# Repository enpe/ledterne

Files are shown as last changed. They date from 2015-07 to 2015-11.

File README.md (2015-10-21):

# LEDterne

## Required Equipment

- Suggested hardware lists:
	1. [mikrocontroller.net][0]
- Atmel AVRISP MKII ([Amazon][1])
- Evaluation board ([ehajo][2], [Pollin][3], [Amazon][4])
- Adapter cable, 10P-to-6P ([mikocontroller.net][7], [Amazon 1][5], [Amazon 2][6])
- Power supply (~9V)
- Bread board ([Amazon][8])
- ATMEGA8-16PU ([Amazon][9])
- Steckbrücken 
- Multimeter
- Resistors
- LEDs (e.g. RGB)
- Software (compiler, etc.) ([mikrocontroller.net][20])

## TODO

- Experiment with LEDs
	- Adjust series resistors for balanced LED brightness of the different colors
	- Try diffusing light from the LEDs
- Add some interesting animations
- Add a push button for switching between a number of animations, constant colors etc.
	- Can use pin PD3's external interrupt capabilities instead of polling one of the other free pins
- Make it battery-driven
- Maybe make the PWM smarter for improved energy saving
	- Alternative 1:
		- Avoid generating interrupts for every single possible step in a PWM cycle
		- Compute only the required timeout periods for all 3×5 outputs instead
	- Alternative 2 (easier than 1):
		- Avoid generating interrupts for every single possible step in a PWM cycle
		- Compute only the required timeout periods for all (currently 32) different duty cycles that we actually use
		- This is not as efficient as alternative 1, but it is much simpler to implement since it is not data-dependent (does not change with the desired LED brightness (i.e. with the animations))
- Maybe improve PWM resolution for smoother fading
- Maybe implement the animations using coroutines/generators instead of letting the animation do the diplay update
	- https://en.wikipedia.org/wiki/Generator_%28computer_science%29
	- http://www.chiark.greenend.org.uk/~sgtatham/coroutines.html

### Battery holder and rod
- Dimensions of [mignon/AA batteries][21]:
	- Diameter:  13.5-14.5 mm
    - Length:    49.2-50.5 mm
- General idea:
    1. Rod of the lantern
    	- Thin aluminum tube (outer diameter <= 10mm).
    	- Drill a small hole near the top end of the rod (wire outlet + hook for
    	  lantern).
    	- Close the top end with a small cap (or leave it open).
    	- Take 2-3 corks and drill holes into the centers to fit the rod.
    	- Cut outside part of the corks to fit (tightly) into the tube of 
    	  battery holder.
    	- Slide the corks over the lower end of the rod.
    	- Insert 2 wires from lower end of the rod to the outlet at the top end.
    2. Battery holder
		- Tube with inner diameter of ~15-16 mm.
		- In the first third of the tube, drill a hole for a small switch.
		- Add 2 wires: one from switch to the lower end of the tube the other
		  from one end of the tube to the other.
		- Connect the switch with one wire of the rod, and connect the remaining
		  two wires
		- Connect upper end of the battery holder with the rod.
		- Fill with 3xAA batteries.
		- Add a spring at the lower end and connect it to the wire.
		- Close lower end with a plastic cap (Lamellenstopfen)
- Other DIY project for battery holders (in no particular order):
	- http://makezine.com/2009/08/14/how-to-free-diy-battery-holders/
	- http://makezine.com/2015/08/02/make-a-stylish-flashlight-out-of-kitchen-trash/
	- http://www.instructables.com/id/Bicycle-Battery-Holder-3-x-AA/
	- http://www.instructables.com/id/Easy-custom-battery-holders/
	- http://www.instructables.com/id/Easy-DIY-Battery-Holder/
	- http://www.instructables.com/id/PVC-tube-battery-AA-battery-holder/
	- http://www.pcbheaven.com/projectpages/DIY_Battery_Pack/

[0]: http://www.mikrocontroller.net/articles/AVR-Tutorial:_Equipment
[1]: http://www.amazon.de/Atmel-Programmer-ATMEL-AVR-ISP-MKII/dp/B00CASCN2S
[2]: http://www.ehajo.de/ateval-atmel-evaluationboard.html 
[3]: http://www.pollin.de/shop/dt/NTI5OTgxOTk-/Bausaetze_Module/Entwicklerboards/ATMEL_Evaluations_Board_V2_0_1_Fertigmodul.html
[4]: http://www.amazon.de/Atmel-Fertiggerät-Atmel-Evaluations-Board-V2-0/dp/B004BMJZ0O
[5]: http://www.amazon.de/Convert-Standard-Adapter-STK500-AVRISP/dp/B00P783JIU
[6]: http://www.amazon.de/Adapter-Kit-10polig-Atmel-Programmer/dp/B004D2TFYI
[7]: http://www.mikrocontroller.net/articles/AVR_In_System_Programmer#ISP
[8]: http://www.amazon.de/Steckbrett-Breadboard-Experimentierboard-Steckplatine-Kontakte/dp/B009P04XWW
[9]: http://www.amazon.de/ATMEGA8-16PU-Atmel-Microcontroller-MEGA-DIP-28/dp/9827046934
[20]: http://www.mikrocontroller.net/articles/AVR_und_Linux
[21]: https://de.wikipedia.org/wiki/Mignon_%28Batterie%29

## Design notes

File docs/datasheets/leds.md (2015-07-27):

# SMD RGB LEDs

- bought from [Segor](http://www.segor.de/#Q%3DLED5252RGB%26M%3D1)
- no clear indication of a model, so no datasheet
- conducted our own measurement of forward voltages given a fixed forward current:

| Fwd current | Fwd voltage R | Fwd voltage G | Fwd voltage B |
|---|---|---|---|
| 20 mA | 2.08 V | 3.39 V | 3.14 V |
| 25 mA | 2.12 V | 3.45 V | 3.21 V |
| 30 mA | 2.15 V | 3.49 V | 3.26 V |

- every single one of the 3 LEDs inside that package can be controlled independently

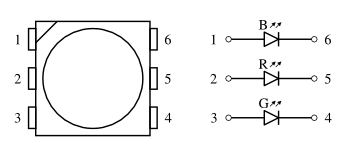
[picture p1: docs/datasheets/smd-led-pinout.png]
LED pinout


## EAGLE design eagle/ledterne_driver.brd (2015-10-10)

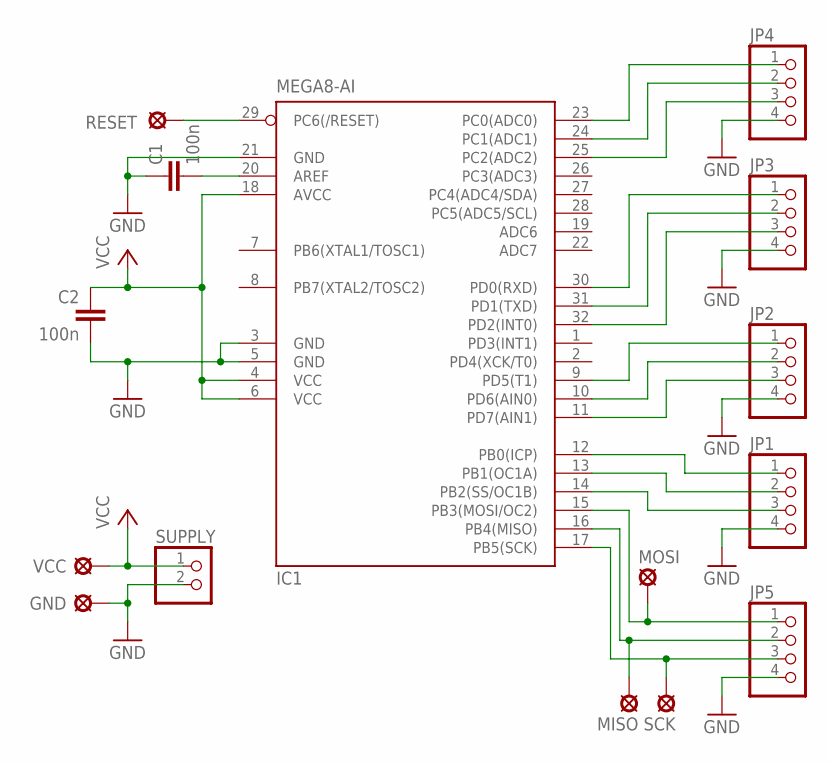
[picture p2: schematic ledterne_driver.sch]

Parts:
C1, C2: 100n; C0805K
GND: LSP10
IC1: MEGA8-AI; TQFP32-08
JP1, JP2, JP3, JP4, JP5: PINHD-1X4/90; 1X04/90
MISO: LSP10
MOSI: LSP10
RESET: LSP10
SCK: LSP10
SUPPLY: PINHD-1X2; 1X02
VCC: LSP10

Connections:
GND: C1.1, C2.2, GND.MP, IC1.3 (GND), IC1.5 (GND), IC1.21 (GND), JP1.4, JP2.4, JP3.4, JP4.4, JP5.4, SUPPLY.2
MISO: IC1.16 (PB4(MISO)), JP5.2, MISO.MP
MOSI: IC1.15 (PB3(MOSI/OC2)), JP5.1, MOSI.MP
unnamed: C1.2, IC1.20 (AREF)
unnamed: IC1.14 (PB2(SS/OC1B)), JP1.3
unnamed: IC1.13 (PB1(OC1A)), JP1.2
unnamed: IC1.12 (PB0(ICP)), JP1.1
unnamed: IC1.11 (PD7(AIN1)), JP2.3
unnamed: IC1.10 (PD6(AIN0)), JP2.2
unnamed: IC1.9 (PD5(T1)), JP2.1
unnamed: IC1.30 (PD0(RXD)), JP3.1
unnamed: IC1.31 (PD1(TXD)), JP3.2
unnamed: IC1.32 (PD2(INT0)), JP3.3
unnamed: IC1.23 (PC0(ADC0)), JP4.1
unnamed: IC1.24 (PC1(ADC1)), JP4.2
unnamed: IC1.25 (PC2(ADC2)), JP4.3
RESET: IC1.29 (PC6(/RESET)), RESET.MP
SCK: IC1.17 (PB5(SCK)), JP5.3, SCK.MP
VCC: C2.1, IC1.4 (VCC), IC1.6 (VCC), IC1.18 (AVCC), SUPPLY.1, VCC.MP

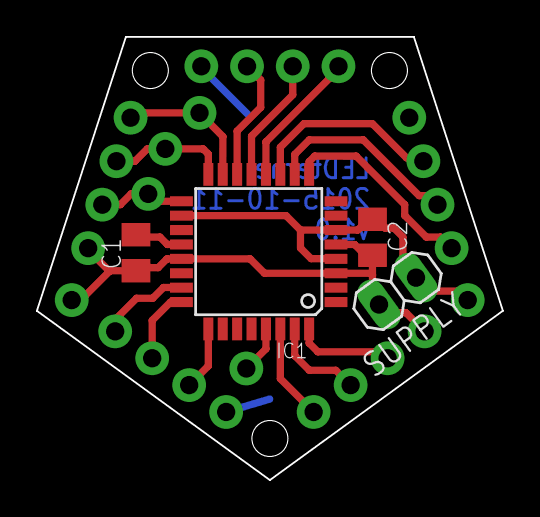
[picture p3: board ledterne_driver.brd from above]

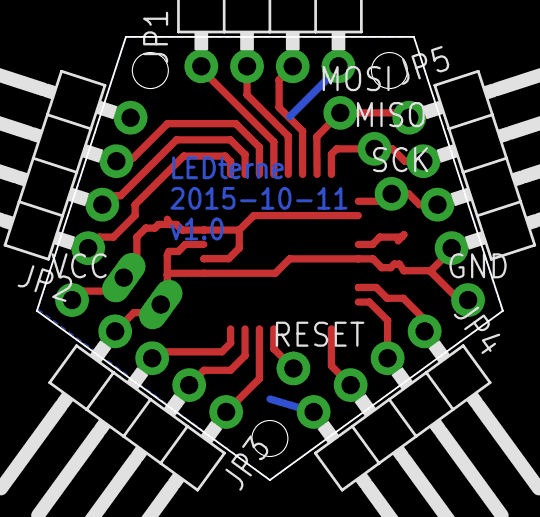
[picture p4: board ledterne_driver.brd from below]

Board: 2 copper layers, 25.9 x 24.6 mm, 15 parts (11 on the bottom side), 19 nets.

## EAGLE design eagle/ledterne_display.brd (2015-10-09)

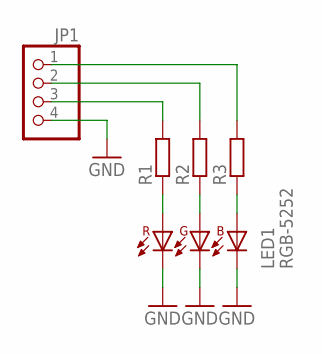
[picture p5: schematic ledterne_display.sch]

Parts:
JP1: PINHD-1X4; 1X04
LED1: RGB-5252; SMD_5252
R1, R2, R3: R-EU_R0805; R0805

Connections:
GND: JP1.4, LED1.P4 (CGREEN), LED1.P5 (CRED), LED1.P6 (CBLUE)
LED_B: JP1.1, R3.2
LED_G: JP1.2, R2.2
LED_R: JP1.3, R1.2
unnamed: LED1.P2 (ARED), R1.1
unnamed: LED1.P3 (AGREEN), R2.1
unnamed: LED1.P1 (ABLUE), R3.1

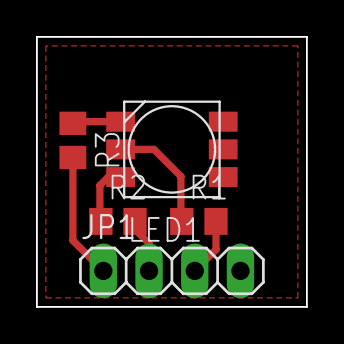
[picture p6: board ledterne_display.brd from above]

Board: 2 copper layers, 15.0 x 15.0 mm, 5 parts (0 on the bottom side), 7 nets.

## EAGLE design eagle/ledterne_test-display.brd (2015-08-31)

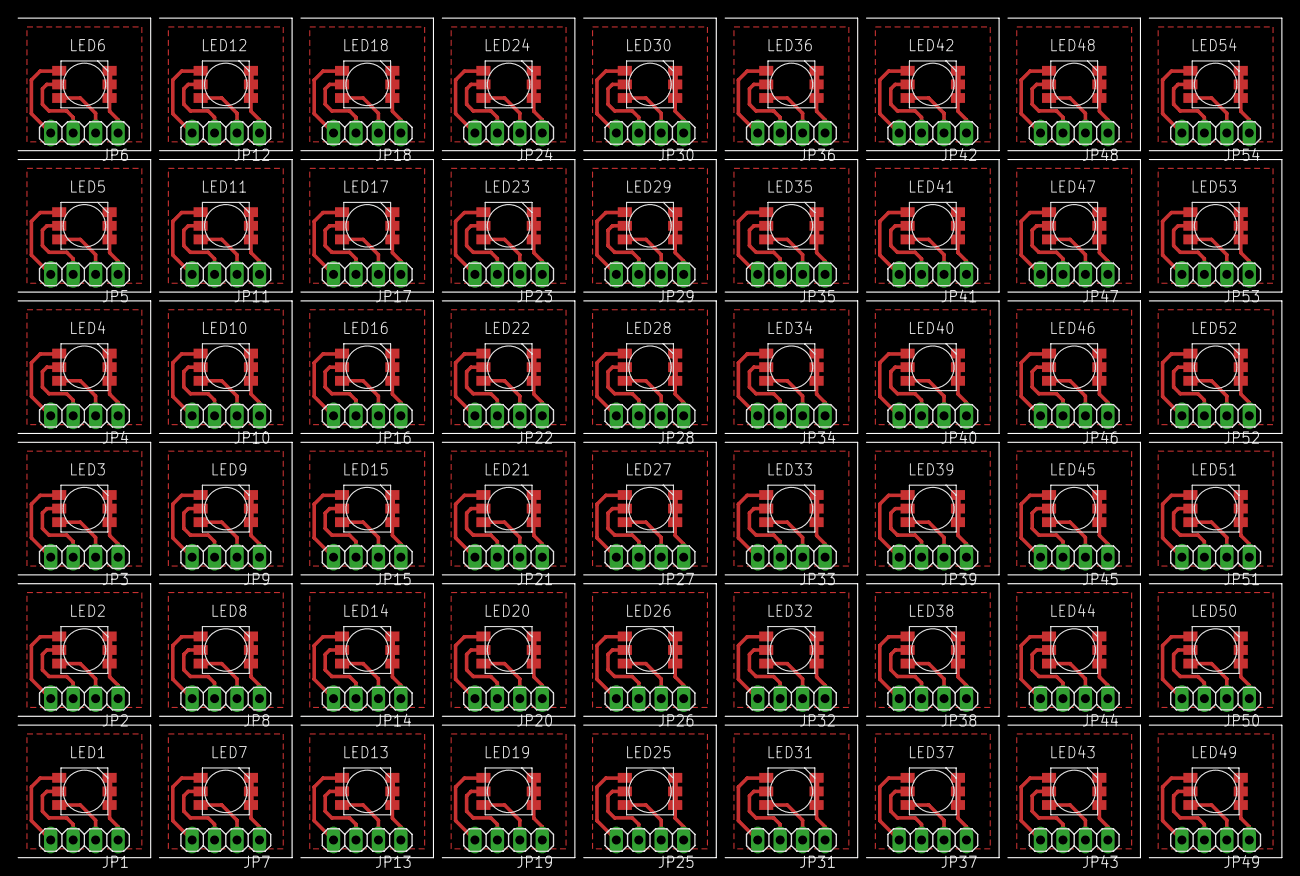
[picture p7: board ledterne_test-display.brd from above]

Board: 2 copper layers, 143.0 x 95.0 mm, 108 parts (0 on the bottom side), 216 nets.

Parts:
JP1, JP2, JP3, JP4, JP5, JP6, JP7, JP8, JP9, JP10, JP11, JP12, JP13, JP14, JP15, JP16, JP17, JP18, JP19, JP20, JP21, JP22, JP23, JP24, JP25, JP26, JP27, JP28, JP29, JP30, JP31, JP32, JP33, JP34, JP35, JP36, JP37, JP38, JP39, JP40, JP41, JP42, JP43, JP44, JP45, JP46, JP47, JP48, JP49, JP50, JP51, JP52, JP53, JP54: 1X04
LED1, LED2, LED3, LED4, LED5, LED6, LED7, LED8, LED9, LED10, LED11, LED12, LED13, LED14, LED15, LED16, LED17, LED18, LED19, LED20, LED21, LED22, LED23, LED24, LED25, LED26, LED27, LED28, LED29, LED30, LED31, LED32, LED33, LED34, LED35, LED36, LED37, LED38, LED39, LED40, LED41, LED42, LED43, LED44, LED45, LED46, LED47, LED48, LED49, LED50, LED51, LED52, LED53, LED54: RGB-5252; SMD_5252

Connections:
GND: JP1.1, LED1.P1, LED1.P2, LED1.P3
GND1: JP2.1, LED2.P1, LED2.P2, LED2.P3
GND2: JP3.1, LED3.P1, LED3.P2, LED3.P3
GND3: JP4.1, LED4.P1, LED4.P2, LED4.P3
GND4: JP5.1, LED5.P1, LED5.P2, LED5.P3
GND5: JP6.1, LED6.P1, LED6.P2, LED6.P3
GND6: JP7.1, LED7.P1, LED7.P2, LED7.P3
GND7: JP8.1, LED8.P1, LED8.P2, LED8.P3
GND8: JP9.1, LED9.P1, LED9.P2, LED9.P3
GND9: JP10.1, LED10.P1, LED10.P2, LED10.P3
GND10: JP11.1, LED11.P1, LED11.P2, LED11.P3
GND11: JP12.1, LED12.P1, LED12.P2, LED12.P3
GND12: JP13.1, LED13.P1, LED13.P2, LED13.P3
GND13: JP14.1, LED14.P1, LED14.P2, LED14.P3
GND14: JP15.1, LED15.P1, LED15.P2, LED15.P3
GND15: JP16.1, LED16.P1, LED16.P2, LED16.P3
GND16: JP17.1, LED17.P1, LED17.P2, LED17.P3
GND17: JP18.1, LED18.P1, LED18.P2, LED18.P3
GND18: JP19.1, LED19.P1, LED19.P2, LED19.P3
GND19: JP20.1, LED20.P1, LED20.P2, LED20.P3
GND20: JP21.1, LED21.P1, LED21.P2, LED21.P3
GND21: JP22.1, LED22.P1, LED22.P2, LED22.P3
GND22: JP23.1, LED23.P1, LED23.P2, LED23.P3
GND23: JP24.1, LED24.P1, LED24.P2, LED24.P3
GND24: JP25.1, LED25.P1, LED25.P2, LED25.P3
GND25: JP26.1, LED26.P1, LED26.P2, LED26.P3
GND26: JP27.1, LED27.P1, LED27.P2, LED27.P3
GND27: JP28.1, LED28.P1, LED28.P2, LED28.P3
GND28: JP29.1, LED29.P1, LED29.P2, LED29.P3
GND29: JP30.1, LED30.P1, LED30.P2, LED30.P3
GND30: JP31.1, LED31.P1, LED31.P2, LED31.P3
GND31: JP32.1, LED32.P1, LED32.P2, LED32.P3
GND32: JP33.1, LED33.P1, LED33.P2, LED33.P3
GND33: JP34.1, LED34.P1, LED34.P2, LED34.P3
GND34: JP35.1, LED35.P1, LED35.P2, LED35.P3
GND35: JP36.1, LED36.P1, LED36.P2, LED36.P3
GND36: JP37.1, LED37.P1, LED37.P2, LED37.P3
GND37: JP38.1, LED38.P1, LED38.P2, LED38.P3
GND38: JP39.1, LED39.P1, LED39.P2, LED39.P3
GND39: JP40.1, LED40.P1, LED40.P2, LED40.P3
GND40: JP41.1, LED41.P1, LED41.P2, LED41.P3
GND41: JP42.1, LED42.P1, LED42.P2, LED42.P3
GND42: JP43.1, LED43.P1, LED43.P2, LED43.P3
GND43: JP44.1, LED44.P1, LED44.P2, LED44.P3
GND44: JP45.1, LED45.P1, LED45.P2, LED45.P3
GND45: JP46.1, LED46.P1, LED46.P2, LED46.P3
GND46: JP47.1, LED47.P1, LED47.P2, LED47.P3
GND47: JP48.1, LED48.P1, LED48.P2, LED48.P3
GND48: JP49.1, LED49.P1, LED49.P2, LED49.P3
GND49: JP50.1, LED50.P1, LED50.P2, LED50.P3
GND50: JP51.1, LED51.P1, LED51.P2, LED51.P3
GND51: JP52.1, LED52.P1, LED52.P2, LED52.P3
GND52: JP53.1, LED53.P1, LED53.P2, LED53.P3
GND53: JP54.1, LED54.P1, LED54.P2, LED54.P3
unnamed: JP2.2, LED2.P4
unnamed: JP2.3, LED2.P5
unnamed: JP1.2, LED1.P4
unnamed: JP1.3, LED1.P5
unnamed: JP1.4, LED1.P6
unnamed: JP2.4, LED2.P6
unnamed: JP3.2, LED3.P4
unnamed: JP3.3, LED3.P5
unnamed: JP3.4, LED3.P6
unnamed: JP4.2, LED4.P4
unnamed: JP4.3, LED4.P5
unnamed: JP4.4, LED4.P6
unnamed: JP5.2, LED5.P4
unnamed: JP5.3, LED5.P5
unnamed: JP5.4, LED5.P6
unnamed: JP6.2, LED6.P4
unnamed: JP6.3, LED6.P5
unnamed: JP6.4, LED6.P6
unnamed: JP7.2, LED7.P4
unnamed: JP7.3, LED7.P5
unnamed: JP7.4, LED7.P6
unnamed: JP8.2, LED8.P4
unnamed: JP8.3, LED8.P5
unnamed: JP8.4, LED8.P6
unnamed: JP9.2, LED9.P4
unnamed: JP9.3, LED9.P5
unnamed: JP9.4, LED9.P6
unnamed: JP10.2, LED10.P4
unnamed: JP10.3, LED10.P5
unnamed: JP10.4, LED10.P6
unnamed: JP11.2, LED11.P4
unnamed: JP11.3, LED11.P5
unnamed: JP11.4, LED11.P6
unnamed: JP12.2, LED12.P4
unnamed: JP12.3, LED12.P5
unnamed: JP12.4, LED12.P6
unnamed: JP13.2, LED13.P4
unnamed: JP13.3, LED13.P5
unnamed: JP13.4, LED13.P6
unnamed: JP14.2, LED14.P4
unnamed: JP14.3, LED14.P5
unnamed: JP14.4, LED14.P6
unnamed: JP15.2, LED15.P4
unnamed: JP15.3, LED15.P5
unnamed: JP15.4, LED15.P6
unnamed: JP16.2, LED16.P4
unnamed: JP16.3, LED16.P5
unnamed: JP16.4, LED16.P6
unnamed: JP17.2, LED17.P4
unnamed: JP17.3, LED17.P5
unnamed: JP17.4, LED17.P6
unnamed: JP18.2, LED18.P4
unnamed: JP18.3, LED18.P5
unnamed: JP18.4, LED18.P6
unnamed: JP19.2, LED19.P4
unnamed: JP19.3, LED19.P5
unnamed: JP19.4, LED19.P6
unnamed: JP20.2, LED20.P4
unnamed: JP20.3, LED20.P5
unnamed: JP20.4, LED20.P6
unnamed: JP21.2, LED21.P4
unnamed: JP21.3, LED21.P5
unnamed: JP21.4, LED21.P6
unnamed: JP22.2, LED22.P4
unnamed: JP22.3, LED22.P5
unnamed: JP22.4, LED22.P6
unnamed: JP23.2, LED23.P4
unnamed: JP23.3, LED23.P5
unnamed: JP23.4, LED23.P6
unnamed: JP24.2, LED24.P4
unnamed: JP24.3, LED24.P5
unnamed: JP24.4, LED24.P6
unnamed: JP25.2, LED25.P4
unnamed: JP25.3, LED25.P5
unnamed: JP25.4, LED25.P6
unnamed: JP26.2, LED26.P4
unnamed: JP26.3, LED26.P5
unnamed: JP26.4, LED26.P6
unnamed: JP27.2, LED27.P4
unnamed: JP27.3, LED27.P5
unnamed: JP27.4, LED27.P6
unnamed: JP28.2, LED28.P4
unnamed: JP28.3, LED28.P5
unnamed: JP28.4, LED28.P6
unnamed: JP29.2, LED29.P4
unnamed: JP29.3, LED29.P5
unnamed: JP29.4, LED29.P6
unnamed: JP30.2, LED30.P4
unnamed: JP30.3, LED30.P5
unnamed: JP30.4, LED30.P6
unnamed: JP31.2, LED31.P4
unnamed: JP31.3, LED31.P5
unnamed: JP31.4, LED31.P6
unnamed: JP32.2, LED32.P4
unnamed: JP32.3, LED32.P5
unnamed: JP32.4, LED32.P6
unnamed: JP33.2, LED33.P4
unnamed: JP33.3, LED33.P5
unnamed: JP33.4, LED33.P6
unnamed: JP34.2, LED34.P4
unnamed: JP34.3, LED34.P5
unnamed: JP34.4, LED34.P6
unnamed: JP35.2, LED35.P4
unnamed: JP35.3, LED35.P5
unnamed: JP35.4, LED35.P6
unnamed: JP36.2, LED36.P4
unnamed: JP36.3, LED36.P5
unnamed: JP36.4, LED36.P6
unnamed: JP37.2, LED37.P4
unnamed: JP37.3, LED37.P5
unnamed: JP37.4, LED37.P6
unnamed: JP38.2, LED38.P4
unnamed: JP38.3, LED38.P5
unnamed: JP38.4, LED38.P6
unnamed: JP39.2, LED39.P4
unnamed: JP39.3, LED39.P5
unnamed: JP39.4, LED39.P6
unnamed: JP40.2, LED40.P4
unnamed: JP40.3, LED40.P5
unnamed: JP40.4, LED40.P6
unnamed: JP41.2, LED41.P4
unnamed: JP41.3, LED41.P5
unnamed: JP41.4, LED41.P6
unnamed: JP42.2, LED42.P4
unnamed: JP42.3, LED42.P5
unnamed: JP42.4, LED42.P6
unnamed: JP43.2, LED43.P4
unnamed: JP43.3, LED43.P5
unnamed: JP43.4, LED43.P6
unnamed: JP44.2, LED44.P4
unnamed: JP44.3, LED44.P5
unnamed: JP44.4, LED44.P6
unnamed: JP45.2, LED45.P4
unnamed: JP45.3, LED45.P5
unnamed: JP45.4, LED45.P6
unnamed: JP46.2, LED46.P4
unnamed: JP46.3, LED46.P5
unnamed: JP46.4, LED46.P6
unnamed: JP47.2, LED47.P4
unnamed: JP47.3, LED47.P5
unnamed: JP47.4, LED47.P6
unnamed: JP48.2, LED48.P4
unnamed: JP48.3, LED48.P5
unnamed: JP48.4, LED48.P6
unnamed: JP49.2, LED49.P4
unnamed: JP49.3, LED49.P5
unnamed: JP49.4, LED49.P6
unnamed: JP50.2, LED50.P4
unnamed: JP50.3, LED50.P5
unnamed: JP50.4, LED50.P6
unnamed: JP51.2, LED51.P4
unnamed: JP51.3, LED51.P5
unnamed: JP51.4, LED51.P6
unnamed: JP52.2, LED52.P4
unnamed: JP52.3, LED52.P5
unnamed: JP52.4, LED52.P6
unnamed: JP53.2, LED53.P4
unnamed: JP53.3, LED53.P5
unnamed: JP53.4, LED53.P6
unnamed: JP54.2, LED54.P4
unnamed: JP54.3, LED54.P5
unnamed: JP54.4, LED54.P6

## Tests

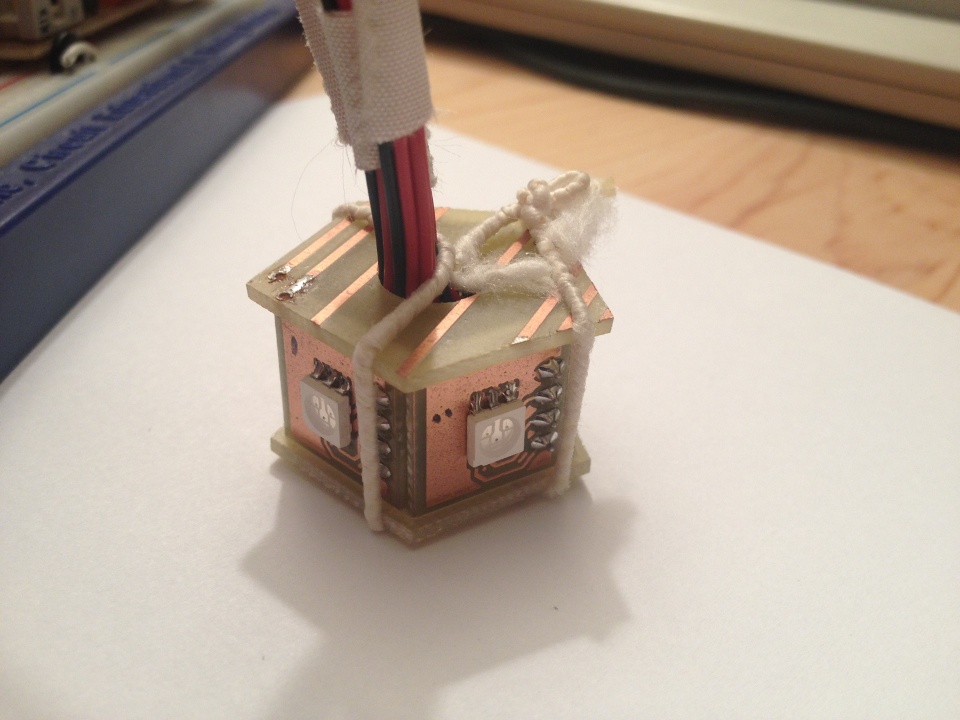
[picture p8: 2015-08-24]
media/ledterne-test-display-11.jpg

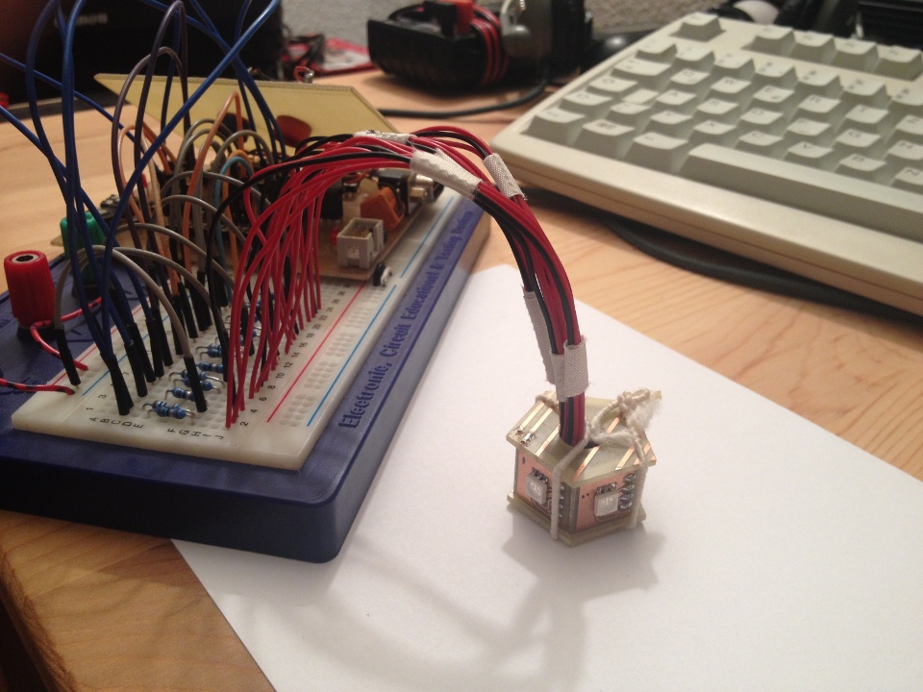
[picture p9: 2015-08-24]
media/ledterne-test-display-12.jpg

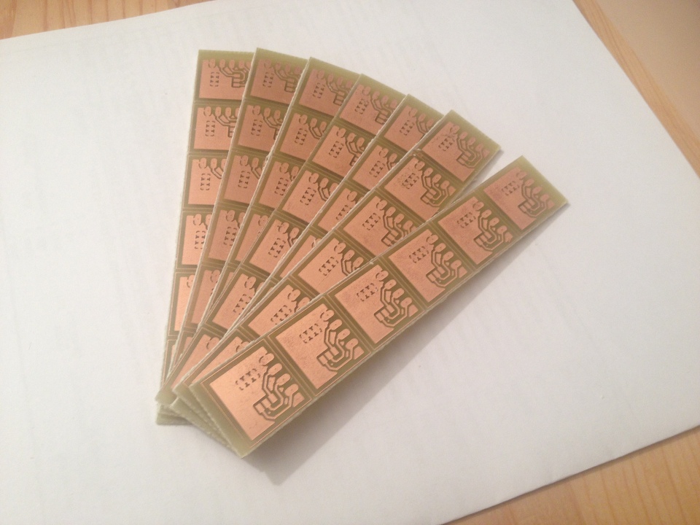
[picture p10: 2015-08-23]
media/ledterne-test-display-02.jpg

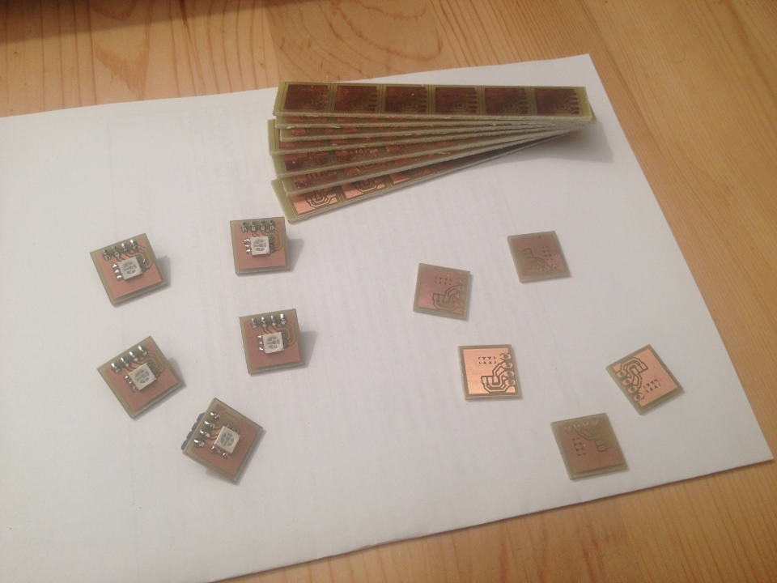
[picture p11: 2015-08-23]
media/ledterne-test-display-05.jpg

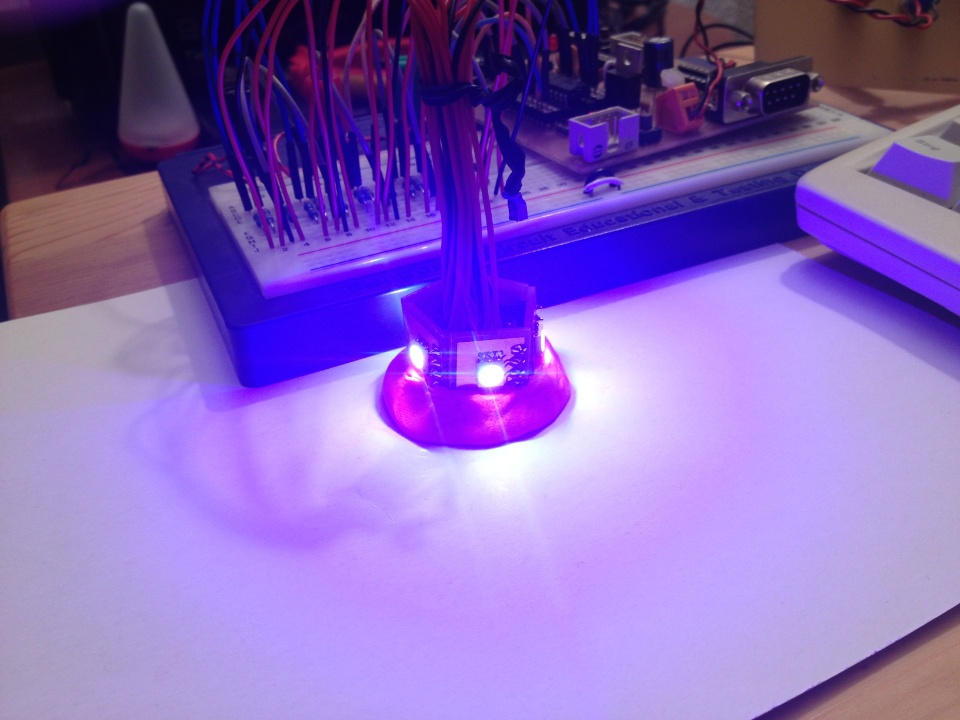
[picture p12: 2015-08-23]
media/ledterne-test-display-09.jpg

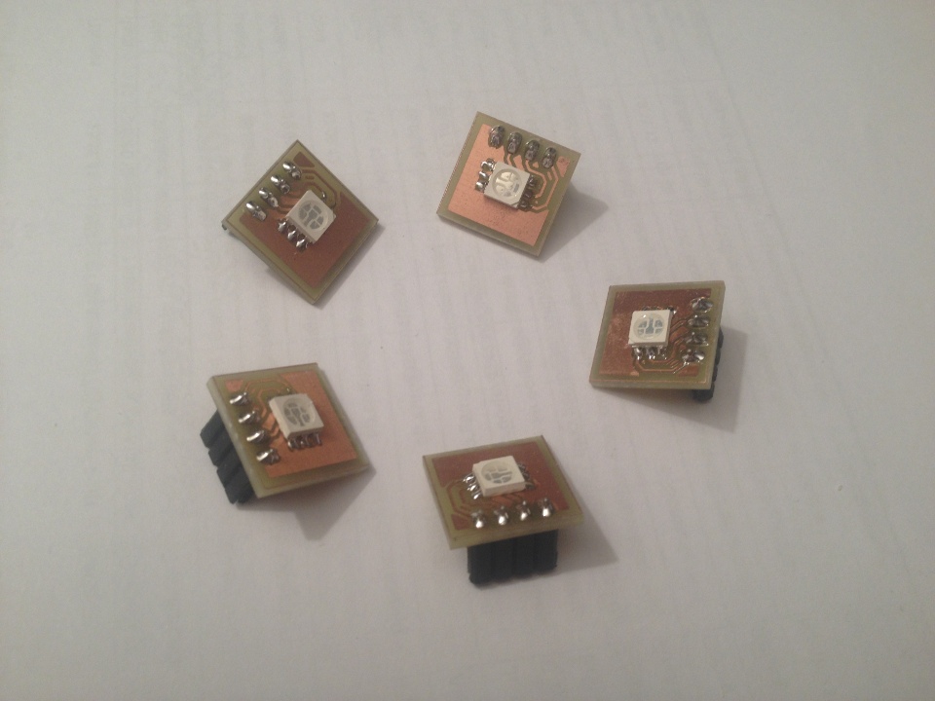
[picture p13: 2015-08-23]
media/ledterne-test-display-04.jpg

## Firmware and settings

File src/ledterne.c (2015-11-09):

/**
 * Dim an array of 5 RGB LEDs using software PWM
 *
 * Platform: ATmega8 @ 8Mhz
 *
 * The basic idea is to rapidly switch an LED on and off in order to change its brightness. The LED
 * is switched on at the beginning of a PWM cycle and switched off later in that cycle (or not
 * switched off at all if maximum brightness is desired). Depending on how long the LED remains lit
 * in that cycle, it will appear brighter or darker. The proportion of "on" time to the length of
 * the complete PWM cycle is the so-called duty cycle.
 *
 * Since the LED is basically flickering, the PWM frequency has to be high enough to make the LED
 * appear to glow with constant brightness to the human eye. We use a PWM frequency of roughly
 * 100 Hz here, with each PWM cycle consisting of 256 steps (i.e. a temporal resolution of 8 bit).
 *
 * A hardware timer is generating an interrupt for each PWM step. The interrupt handler then
 * decides, based on the current position in the PWM cycle and the desired LED brightness, whether
 * to switch the LED on or off.
 *
 * The human eye does not perceive linear changes in brightness as linear but rather
 * logarithmically. For a perceived linear change in LED brightness we thus need to map the desired
 * LED brightness to an appropriate PWM duty cycle by applying a power function. This mapping is
 * done using a precomputed lookup table.
 */

// clock frequency
#ifndef F_CPU
#define F_CPU 8000000L
#endif

#include "animations.h"
#include "ledterne.h"

#include <inttypes.h>
#include <avr/io.h>
#include <avr/interrupt.h>
#include <string.h>
#include <util/delay.h>


// LED outputs (connected to the anodes)
#define PORT_0 PORTB
#define PIN_R0 PB2
#define PIN_G0 PB1
#define PIN_B0 PB0
#define PORT_1 PORTD
#define PIN_R1 PD7
#define PIN_G1 PD6
#define PIN_B1 PD5
#define PORT_2 PORTD
#define PIN_R2 PD2
#define PIN_G2 PD1
#define PIN_B2 PD0
#define PORT_3 PORTC
#define PIN_R3 PC2
#define PIN_G3 PC1
#define PIN_B3 PC0
#define PORT_4 PORTB
#define PIN_R4 PB5
#define PIN_G4 PB4
#define PIN_B4 PB3

// determine data direction register for port p
#define DDR( p ) ( *( &p - 1 ) )


// lookup table for converting LED intensities to PWM steps (brighter LED requires the output to
// stay on for more steps)
uint8_t g_pwm[ MAX_INTENSITY + 1 ] =
{
	  0,   1,   1,   1,   2,   2,   3,   3,
	  4,   5,   6,   7,   9,  10,  12,  15,
	 17,  21,  25,  30,  36,  43,  51,  61,
	 73,  87, 104, 125, 149, 178, 213, 255,
};


typedef struct
{
	uint8_t r;
	uint8_t g;
	uint8_t b;	
}
ledIntensity_t;

ledIntensity_t g_intensity[ NUM_PIXELS ];

// flag for updating the frame (i.e. for advancing the color animation one step)
volatile int g_frameUpdateRequired = 0;


/**
 * @brief Set RGB LED intensities for display
 */
void setIntensity( uint8_t pixelIndex, uint8_t r, uint8_t g, uint8_t b )
{
	if( pixelIndex >= NUM_PIXELS )
	{
		return;
	}

	if( r <= MAX_INTENSITY )
	{
		g_intensity[ pixelIndex ].r = g_pwm[ r ];
	}

	if( g <= MAX_INTENSITY )
	{
		g_intensity[ pixelIndex ].g = g_pwm[ g ];
	}

	if( b <= MAX_INTENSITY )
	{
		g_intensity[ pixelIndex ].b = g_pwm[ b ];
	}
}


/**
 * @brief Interrupt handler for a single PWM step
 *
 * This updates the LED outputs to achieve the currently selected intensities for each channel.
 */
ISR( TIMER2_COMP_vect )
{
	static uint8_t pwmStep = 0;

	if( pwmStep < g_intensity[ 0 ].g ) { PORT_0 |= (1<<PIN_G0); } else { PORT_0 &= ~(1<<PIN_G0); }
	if( pwmStep < g_intensity[ 0 ].r ) { PORT_0 |= (1<<PIN_R0); } else { PORT_0 &= ~(1<<PIN_R0); }
	if( pwmStep < g_intensity[ 0 ].b ) { PORT_0 |= (1<<PIN_B0); } else { PORT_0 &= ~(1<<PIN_B0); }

	if( pwmStep < g_intensity[ 1 ].g ) { PORT_1 |= (1<<PIN_G1); } else { PORT_1 &= ~(1<<PIN_G1); }
	if( pwmStep < g_intensity[ 1 ].r ) { PORT_1 |= (1<<PIN_R1); } else { PORT_1 &= ~(1<<PIN_R1); }
	if( pwmStep < g_intensity[ 1 ].b ) { PORT_1 |= (1<<PIN_B1); } else { PORT_1 &= ~(1<<PIN_B1); }

	if( pwmStep < g_intensity[ 2 ].g ) { PORT_2 |= (1<<PIN_G2); } else { PORT_2 &= ~(1<<PIN_G2); }
	if( pwmStep < g_intensity[ 2 ].r ) { PORT_2 |= (1<<PIN_R2); } else { PORT_2 &= ~(1<<PIN_R2); }
	if( pwmStep < g_intensity[ 2 ].b ) { PORT_2 |= (1<<PIN_B2); } else { PORT_2 &= ~(1<<PIN_B2); }

	if( pwmStep < g_intensity[ 3 ].g ) { PORT_3 |= (1<<PIN_G3); } else { PORT_3 &= ~(1<<PIN_G3); }
	if( pwmStep < g_intensity[ 3 ].r ) { PORT_3 |= (1<<PIN_R3); } else { PORT_3 &= ~(1<<PIN_R3); }
	if( pwmStep < g_intensity[ 3 ].b ) { PORT_3 |= (1<<PIN_B3); } else { PORT_3 &= ~(1<<PIN_B3); }

	if( pwmStep < g_intensity[ 4 ].g ) { PORT_4 |= (1<<PIN_G4); } else { PORT_4 &= ~(1<<PIN_G4); }
	if( pwmStep < g_intensity[ 4 ].r ) { PORT_4 |= (1<<PIN_R4); } else { PORT_4 &= ~(1<<PIN_R4); }
	if( pwmStep < g_intensity[ 4 ].b ) { PORT_4 |= (1<<PIN_B4); } else { PORT_4 &= ~(1<<PIN_B4); }

	// Since it is an uint8, this counter overflows at 255. This is desired behaviour. It makes the
	// counter run from 0 to 255, i.e. it makes a complete PWM cycle consist of 256 single steps.
	pwmStep += 1;
}


/**
 * @brief Interrupt handler for frame tick
 *
 * This signals the main program that the animations needs to be advanced one step
 */
ISR( TIMER1_COMPA_vect )
{
	g_frameUpdateRequired = 1;
}


/**
 * @Brief Set up timer that triggers an interrupt for every single PWM step
 */
void pwmTimerInit()
{
	// prescaler for 8 bit timer: 1/8 clock frequency
	TCCR2 |= (1<<CS21);

	// Clear Timer on Compare (CTC):
	// reset counter TCNT2 when it reaches the value in OCR2
	TCCR2 |= (1<<WGM21);

	// frequency of timer interrupts: ca. 25.6 kHz
	//
	//    f = F_CPU / (PRESCALER * (1 + OCR2))
	// OCR2 = F_CPU / (f * PRESCALER) - 1
	//
	// Since a complete PWM cycle consists of 256 single steps (see the PWM step counter in the
	// associated interrupt handler) this leaves us with a PWM frequency of roughly
	//
	// f_PWM = 25.6 kHz / 256
	//       = 100 Hz .
	//
	OCR2 = 38;

	// enable interrupt on reaching the reference value in OCR2
	TIMSK |= (1<<OCIE2);
}


void animationTimerInit()
{
	// prescaler for 16 bit timer: 1/1024 clock frequency
	TCCR1B |= (1<<CS12) | (1<<CS10);

	// Clear Timer on Compare (CTC):
	// reset counter TCNT1 when it reaches the value in OCRA1
	TCCR1B |= (1<<WGM12);

	// frequency of timer interrupts: ca. 15 Hz
	//
	//     f = F_CPU / (PRESCALER * (1 + OCR1A))
	// OCRA1 = F_CPU / (f * PRESCALER) - 1
	OCR1A = 520;

	// enable interrupt on reaching the reference value in OCR1A
	TIMSK |= (1<<OCIE1A);
}


void setAnimationTimer( uint16_t v )
{
	OCR1A = v;
}


int main( void )
{
	// configure LED pins as outputs, disable by default
	DDR( PORT_0 ) |=    (1<<PIN_R0) | (1<<PIN_G0) | (1<<PIN_B0);
	PORT_0        &= ~( (1<<PIN_R0) | (1<<PIN_G0) | (1<<PIN_B0) );
	DDR( PORT_1 ) |=    (1<<PIN_R1) | (1<<PIN_G1) | (1<<PIN_B1);
	PORT_1        &= ~( (1<<PIN_R1) | (1<<PIN_G1) | (1<<PIN_B1) );
	DDR( PORT_2 ) |=    (1<<PIN_R2) | (1<<PIN_G2) | (1<<PIN_B2);
	PORT_2        &= ~( (1<<PIN_R2) | (1<<PIN_G2) | (1<<PIN_B2) );
	DDR( PORT_3 ) |=    (1<<PIN_R3) | (1<<PIN_G3) | (1<<PIN_B3);
	PORT_3        &= ~( (1<<PIN_R3) | (1<<PIN_G3) | (1<<PIN_B3) );
	DDR( PORT_4 ) |=    (1<<PIN_R4) | (1<<PIN_G4) | (1<<PIN_B4);
	PORT_4        &= ~( (1<<PIN_R4) | (1<<PIN_G4) | (1<<PIN_B4) );

	pwmTimerInit();
	animationTimerInit();

	uint8_t i;

	// intially switch all pixels off
	for( i = 0; i < NUM_PIXELS; i++ )
	{
		setIntensity( i, 0, 0, 0 );
	}

	// globally enable interrupts
	sei();


	AnimationModule const animation[] =
	{
		{
			.programType = ColoredConveyor,
			.repetitions = 12,
			.timerPeriod = 520,
		},
		{
			.programType = MixedColorBlending,
			.repetitions = 1,
			.timerPeriod = 520,
		},
		{
			.programType = KnightRider,
			.repetitions = 2,
			.timerPeriod = 520 * 2,
		},
#if 0
		{
			.programType = TestDisplays,
			.repetitions = 1,
			.timerPeriod = 520 * 2,
		},
#endif
	};

	// compute number of modules in the animation
	uint8_t numModules = sizeof( animation ) / sizeof( AnimationModule );

	uint8_t currentModuleIndex = numModules - 1; // HACK: needed to start with the first module
	uint8_t repetitions = 0;
	AnimationModule const* currentModule = NULL;
	void* currentProgram = NULL;

	void (*programDestroyFunc)( void* ) = NULL;
	uint8_t (*programExecuteFunc)( void* ) = NULL;

	while( 1 )
	{
		if( g_frameUpdateRequired )
		{
			g_frameUpdateRequired = 0;

			// load next module if the current one has finished playing completely
			if( repetitions == 0 )
			{
				// destroy the previous module's program if one exists
				if( currentProgram )
				{
					(*programDestroyFunc)( currentProgram );
				}

				// select next module (start at beginning if we reached the module list's end)
				currentModuleIndex += 1;
				if( currentModuleIndex == numModules )
				{
					currentModuleIndex = 0;
				}

				currentModule = &animation[ currentModuleIndex ];
				repetitions = currentModule->repetitions;

				// instantiate the current module's program
				switch( currentModule->programType )
				{
					case MixedColorBlending:
						currentProgram = MixedColorBlending_create();
						programDestroyFunc = &MixedColorBlending_destroy;
						programExecuteFunc = &MixedColorBlending_execute;
						break;

					case KnightRider:
						currentProgram = KnightRider_create();
						programDestroyFunc = &KnightRider_destroy;
						programExecuteFunc = &KnightRider_execute;
						break;

					case ColoredConveyor:
						currentProgram = ColoredConveyor_create();
						programDestroyFunc = &ColoredConveyor_destroy;
						programExecuteFunc = &ColoredConveyor_execute;
						break;

					case TestDisplays:
						currentProgram = TestDisplays_create();
						programDestroyFunc = &TestDisplays_destroy;
						programExecuteFunc = &TestDisplays_execute;
						break;

				}

				setAnimationTimer( currentModule->timerPeriod );
			}

			// execute the current module's program
			uint8_t programFinished = (*programExecuteFunc)( currentProgram );


			if( programFinished )
			{
				repetitions -= 1;
			}
		}
	}

	return 0;
}

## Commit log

2015-07-13 Replace ramp up/down hack
    Instead of building the up/down motion into the lookup table,
    the animation is now completely done in the function that
    controls the LED brightness values.
    [ledterne.c]
2015-07-13 Fix typo in comments
    [ledterne.c]
2015-07-13 Replace busy wait with interrupt-driven frame tick
    Every frame tick advances the color animation one step.
    The 16-bit timer that was previously used for the PWM is now
    replaced by an 8-bit timer. The 16-bit timer is instead used for
    generating the frame tick. This was necessary because the
    required compare values for the frame tick timer would not fit
    into an 8-bit register.
    [ledterne.c]
2015-07-18 Add support for 4 more RGB LED outputs
    All 5 LEDs currently show the same colors even though separate
    control of every single LED is already possible in the code.
2015-07-19 Make ramp functions reusable
    The maximum value is not hard-coded anymore.
    The functions also reside in a separate file now. This will
    hopefully prevent clutter in the main program file.
    [ledterne.c]
2015-07-19 Refactor up/down ramp animation into object function
    This releases the caller from handling internal implementation
    details (in this case: the variable that keeps track of the
    current direction).
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2015-07-19 Replace explicit setting of single pixels with loops
    [ledterne.c]
2015-07-19 Refactor color blending animation
    Instead of repeatedly being called in the main program, this is
    now a standalone animation block that sets the desired LED
    colors all by itself.
    This should make it easier to add similar animations blocks
    without being forced to repeating the same boilerplate code in
    the main program over and over again.
2015-07-19 Use function pointers for animation destruction and execution
    This saves us dealing with switches for the animation program
    type all the time.
    It works but still does not look quite right (generates compiler
    warnings). This might need fixing.
    [ledterne.c]
2015-07-19 Remove Knight Rider's hard-coded fade intensities
    The values are now computed relative to the given maximum LED
    intensity. The result should still be the same as before.
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2015-07-19 Remove superfluous parameter from animation program constructor
    The maximum LED brightness is known inside the animations
    programs anyway. No need to pass it as parameter. The other
    animation programs do not do this either.
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2015-08-06 - Added rough sketches of the schematics and board layout.
    [ledterne_display.brd, ledterne_display.sch, ledterne_driver.brd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]
2015-08-07 - Added possible routing (one layer only).
    [ledterne_display.brd, ledterne_display.sch]
2015-08-08 Clean up the schematic a little bit
    Making everything a bit more compact and using less wires.
    [ledterne_display.sch]
2015-08-08 Assign net names to the LED inputs
    [ledterne_display.brd, ledterne_display.sch]
2015-08-08 Update routing to be more compact
    [ledterne_display.brd, ledterne_display.sch]
2015-08-09 Change driver board to match the display board size
    5 display boards will be arranged in an upright position forming
    a cylinder with a pentagonal base. The driver board is a pentagon
    that then acts as sort of lid for this cylinder.
    [ledterne_driver.brd]
2015-08-09 Add connectors to the driver board
    These connectors will allow the display boards to attach to the
    driver board.
    Note that this is just a very rough sketch for demonstrating the
    basic idea. The exact placement and type of connectors will have
    to be fine-tuned later.
    [ledterne_driver.brd, ledterne_driver.sch]
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2015-08-31 Add EAGLE layout for the test display board
    This is basically a breakout board for the SMD LEDs.
    [ledterne_test-display.brd]
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2015-10-03 Start connecting the components of the driver.
    [ledterne_driver.brd, ledterne_driver.sch]
2015-10-03 Add connector for supply voltage
    [ledterne_driver.brd, ledterne_driver.sch]
2015-10-03 Increase pinhead's diameter for easier soldering/drilling
    [ledterne_driver.brd, ledterne_driver.sch]
2015-10-04 Alternative routing for driver board
    [ledterne_driver.brd, ledterne_driver.sch]
2015-10-04 Replace ISP connector with solder pads
    [ledterne_driver.brd, ledterne_driver.sch]
2015-10-04 Place ISP solder pads on the board
    [ledterne_driver.brd]
2015-10-04 Add ground plane on bottom side
    [ledterne_driver.brd]
2015-10-04 Slightly shrink the ISP solder pads
    [ledterne_driver.brd, ledterne_driver.sch]
2015-10-04 Move MOSI solder pad away from board's corner
    We might need this place for an additional mount.
    [ledterne_driver.brd]
2015-10-05 Add capacitor values
    [ledterne_driver.brd, ledterne_driver.sch]
2015-10-06 Clean up the schematic a little
    [ledterne_driver.brd, ledterne_driver.sch]
2015-10-08 Increase driver board's side length to 16 mm
    [ledterne_driver.brd]
2015-10-08 Replace ISP solder pads with through-hole pins
    [ledterne_driver.brd, ledterne_driver.sch]
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2015-10-08 Switch to a slightly larger capacitor package
    [ledterne_driver.brd, ledterne_driver.sch]
2015-10-08 Finally fix the routing again
    [ledterne_driver.brd]
2015-10-09 Increase width of display board's outline
    [ledterne_display.brd]
2015-10-09 Adjust placement of display board's connector
    The connector is now placed in such way that, when connecting
    the display board with the driver board by using a right-angle
    pin header, the display board's borders are flush with the
    driver board's borders.
    [ledterne_display.brd]
2015-10-09 Add ground plane on display board
    [ledterne_display.brd]
2015-10-09 Limit diameter of display board's drills
    [ledterne_display.brd]
2015-10-10 Add drills for attaching mounts to the driver board
    [ledterne_driver.brd]
2015-10-10 Add driver board's name and version as text labels
    [ledterne_driver.brd]
2015-10-10 Guard ISP pin connectors against routes on bottom layer
    We want to place these connectors on the board's bottom layer,
    so we do not want any bottom routes to be connected. Only
    soldering on the top layer is allowed here and we do not have
    connected vias available.
    [ledterne_driver.brd]
2015-10-10 Slightly increase distance between ISP solder pads and other pads
    [ledterne_driver.brd]
2015-10-10 Move driver's mount drills slightly away from borders
    [ledterne_driver.brd]
2015-10-10 Limit diameter of driver board's drills
    [ledterne_driver.brd]
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2015-10-28 Fix conveyor animation
    The rotation and fading speeds are now adjusted so that a full
    cycle of the animation blends seemlessly in time.
    [ledterne.c]
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2015-11-09 Slow down the animation clock instead of skipping frames
    Animations that need to run at lower frame rates can now simply
    adjust the animation clock accordingly instead of slowing the
    animation down by internally skipping frames.
    This also makes it possible to increase the frame rate, of
    course.
    [ledterne.c]
